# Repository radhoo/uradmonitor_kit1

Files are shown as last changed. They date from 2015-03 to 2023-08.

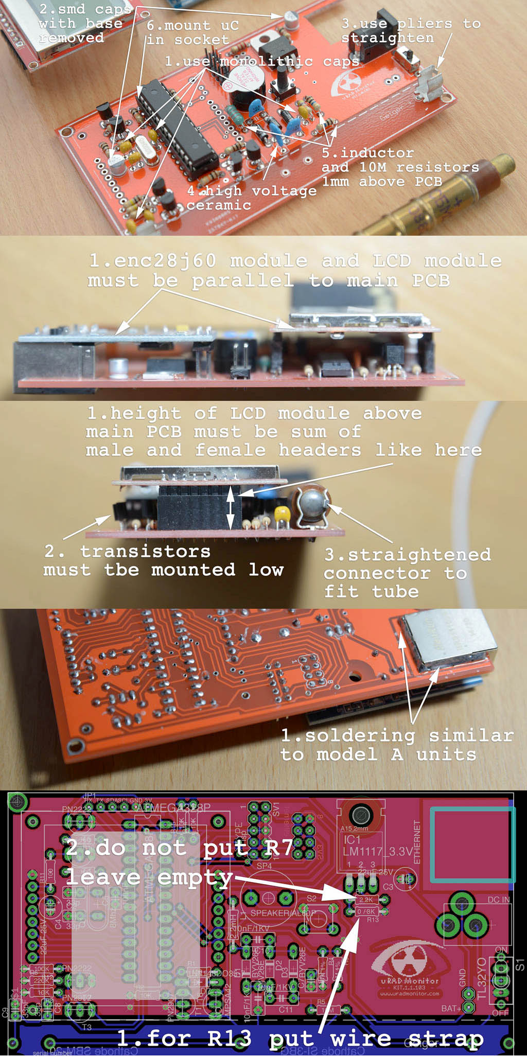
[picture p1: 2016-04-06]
pcb/pcb-1.1.103/pictures/instructions.jpg

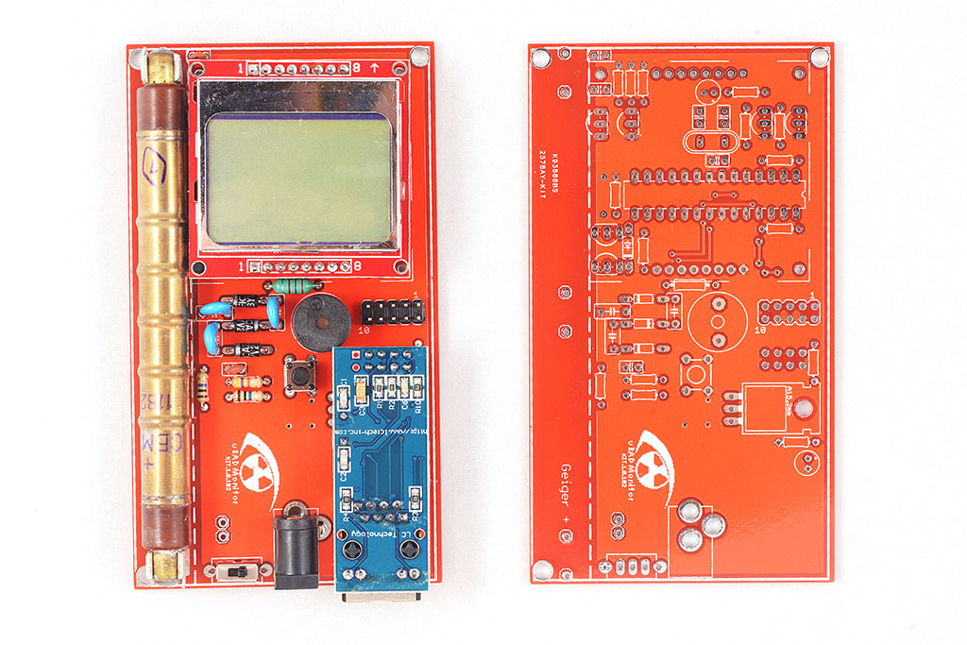
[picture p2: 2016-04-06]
pcb/pcb-1.1.103/pictures/uRADMonitor_KIT1_6.jpg

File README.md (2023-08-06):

# uradmonitor_kit1
A hackable open source DIY Geiger Counter Kit 
with a network interface to the uRADMonitor servers

Project page: http://www.uradmonitor.com/open-source-uradmonitor-kit1/
See the wiki for more details.

Finalist in Hackaday Prize 2017: https://www.uradmonitor.com/finalist-in-hackaday-prize-2017/

DIY KIT1 variants created by makers worldwide:


Firmware compile guide for Windows: https://www.uradmonitor.com/a-tutorial-how-to-compile-kit1-firmware-on-a-windows-machine/ by Wolferl.

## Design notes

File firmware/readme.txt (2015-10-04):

For those of you that want to avoid the hassle of downloading and compiling the code, I have included the compiled code below. 
One variant is a simple, offline code that works without the Ethernet module: uradmonitor-kit1-local.hex 
while the second adds support for Ethernet as well: uradmonitor-kit1-eth.hex

Some instructions on how to burn a hex firmware file to the microcontroller are provided here: 
http://www.pocketmagic.net/how-to-set-the-avr-fusebits/

To correctly burn any of the two hex files into your microcontroller, see the prog.sh script that invokes avrdude. It also sets the fuses for the 8MHz crystal.

Important note:
Code for joining the uRADMonitor network is currently available only on request due to sensitive security details involved. With this code a valid uRADMonitor device ID is also provided.

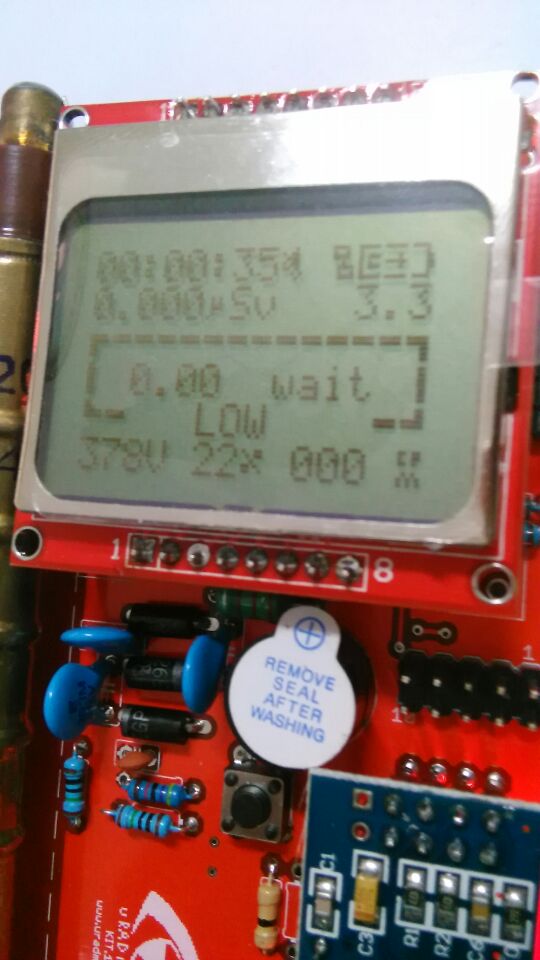
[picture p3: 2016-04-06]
uradmonitor-kit-1.1.103.jpg

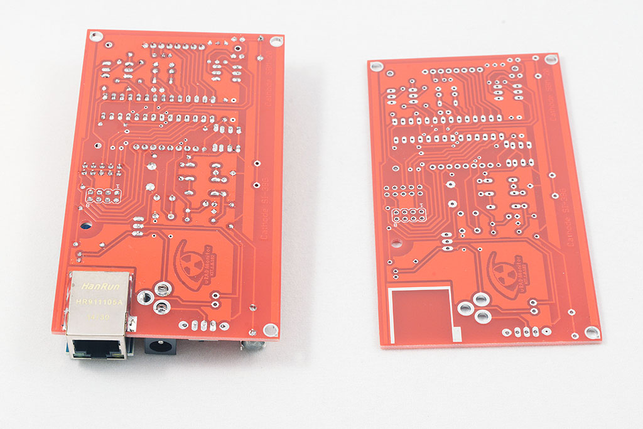
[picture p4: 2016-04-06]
pcb/pcb-1.1.103/pictures/uRADMonitor_KIT1_5.jpg

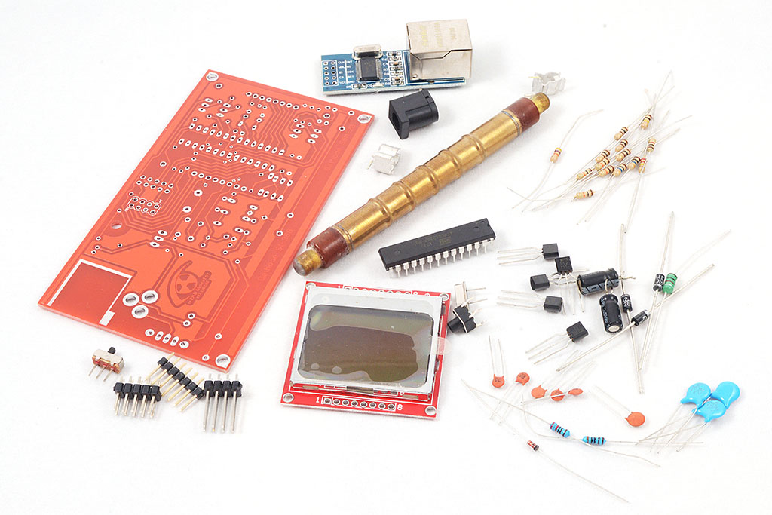
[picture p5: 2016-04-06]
pcb/pcb-1.1.103/pictures/uRADMonitor_KIT1_1.jpg

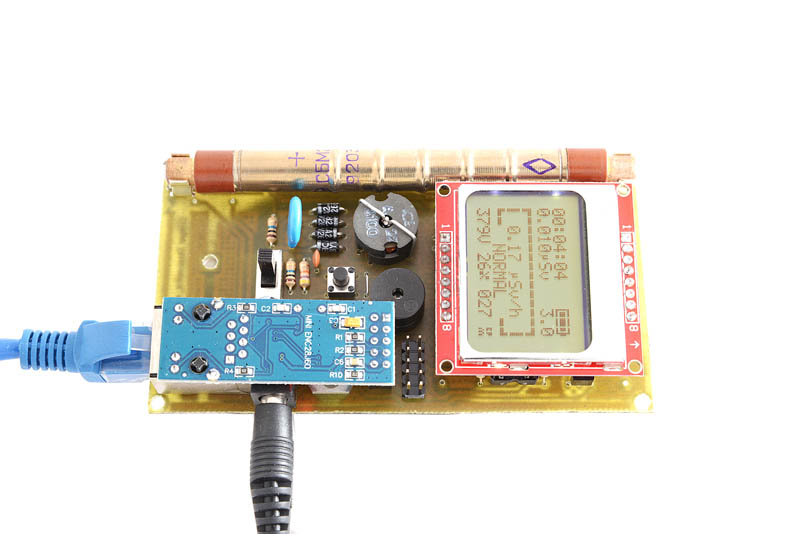
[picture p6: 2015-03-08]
uradmonitor-kit-1.0.jpg

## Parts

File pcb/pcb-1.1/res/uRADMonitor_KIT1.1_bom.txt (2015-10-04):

Partlist exported from /Users/radhoo/Work/pocketmagic/uradmonitor_KIT1/pcb-1.1/dosimeter.sch at 04/10/15 20:23

Assembly variant: 

Qty Value         Device              Parts                                     
1                 LM317TL             IC1                                       
8                 PINHD-1X1           BAT+, BATGND, JP1, JP2, JP3, JP4, JP5, JP6
1                 TAC_SWITCHPTH       S2                                        
1   1N4148DO35-7  1N4148DO35-7        D7                                        
1   2.1MMJACKTHM  2.1MMJACKTHM        U$2                                       
1   2.2K          R-EU_0204/7         R13                                       
1   2.2mH         L-EU0207/10         L1                                        
1   2N2222        2N2222              T2                                        
2   2N2907        2N2907              T3, T6                                    
2   2n2222        2N2222-NPN-TO92-EBC T4, T5                                    
1   3K            R-EU_0204/7         R7                                        
1   8Mhz          XTAL/S              Q1                                        
4   10K           R-EU_0204/7         R2, R8, R14, R15                          
1   10M           R-EU_0204/7         R5                                        
1   10M 1%        R-EU_0204/7         R3                                        
3   10nF/1KV      C5/3                C6, C10, C11                              
1   15nF          C2.5/2              C7                                        
1   22uF 50V      CPOL-EUE2-5         C3                                        
3   33p           C2.5/2              C1, C2, C8                                
1   33pF          C2.5/2              C9                                        
1   47K 1%        R-EU_0204/7         R4                                        
1   47uF 16V      CPOL-EUE2-5         C4                                        
4   100           R-EU_0204/7         R1, R9, R10, R11                          
1   100K          R-EU_0204/7         R12                                       
1   100nF         C2.5/2              C5                                        
1   220K          R-EU_0204/7         R6                                        
1   ATMEGA328P    MEGA8-P             ATMEGA328P                                
3   BYV26E        1N40047.5           D1, D2, D3                                
1   MPSA42        2N2222              T1                                        
1   NOKIA5110     NOKIA5110           U$1                                       
1   SPEAKER/AL60P SPEAKER/AL60P       SP4                                       
1   TL32YO        TL32YO              S1                                        
1   ethernet      MA04-2              SV3                                       
1   isp           MA05-2              SV1

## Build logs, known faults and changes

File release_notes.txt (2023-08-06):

HW 1.2.107 "ARTIFEX" SW124
- ne 10K resistor between data in and vcc pin of the display, it will support better compatibility with different LCD boards, there are more manufacturers doing boards different way and some of them doesn't work properly, this should solve the problem for all.
- footprint space for new Geiger tubes, the "M4011" and the " J305" added.
- factors for the two new tubes added.
- new tubes implemented on the server side

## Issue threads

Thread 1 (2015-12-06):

Tube connectors missing in BOM

berezovskyi, 2015-12-06:
Hi, I looked at the https://github.com/radhoo/uradmonitor_kit1/blob/master/pcb-1.1/res/uRADMonitor_KIT1.1_bom.txt#L7 but found no connectors (slots) in BOM for the SBM-20 tube.

Do you have any hints on how to find them?

radhoo, 2015-12-13:
Hello, please use fuse holders, 6mm diameter as connectors.

berezovskyi, 2015-12-20:
Brilliant, @radhoo! I think the best way for others to find them would be to search for *6.3mm (1/4") fuse clip*

berezovskyi, 2015-12-20:
Littelfuse 01020071Z seems to be a good generic part

radhoo, 2015-12-20:
Yes, and there are very affordable ones on Ebay as well.  I got a bag of
100pcs for just a few dollars.

On Sun, Dec 20, 2015 at 11:58 PM, Andrew Berezovskyi <
notifications@github.com> wrote:

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

Closed 2017-08-05.

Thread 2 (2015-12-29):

Routing incomplete?

madmax76, 2015-12-29:
Hi,

Opening the 1.1 board in Eagle shows me that some traces have not been routed. Is that correct? After manually checking, it seems all is oke, but I want to etch the board, so I need to make sure that no errors are in the board. Seems like the Nokia LCD display has some magic via's on it, that I am unaware of.

Best regards,
Max

radhoo, 2015-12-29:
That is correct, the Nokia display continues those routes. No mistakes here, feel free to etch.

Closed 2015-12-29.

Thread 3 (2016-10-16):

can not remove "old" stations from uradmonitor map

twanek, 2016-10-16:
**simptome:**
when flashing the new firmware, if one does not set the "do not clear eeprom" fusebit parameter, the server allocates a new device id.
so, every time when the firmware is flashed, a "new' device will appear on the map, and the "old" ones still remain. this can clutter the map and could suggest improper device numbers / city. posteriorly impossible for the user to remove them...

**solution:**
it would be nice to have a delete button on the dashboard (or some other way) to delete fictional stations from the map. (or delete automatically the units which are offline more than x days)

jetty840, 2017-06-14:
I've also had it happen once when the fuse is set correctly, but the upload comms corrupted.  Delete feature would be good.

radhoo, 2017-06-26:
The solution was implemented on the server side . ID of "Old" units are being reallocated to new requesters. An ID is labeled "Old" if more than 30 days have passed since the last data was received.

Closed 2017-06-26.

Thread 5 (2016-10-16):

in firmware v122, temperature value has only 1 degree resolution

twanek, 2016-10-16:
i'm not sure if it is from wrong compilation settings, or a bug in the code, but the temperature value is displayed only as int on my device display / local site / server.
so, it has only one degree resolution...  :(

reidor, 2016-12-05:
Replace the following line in bme280.cpp as shown in order to evaluate the temperatur as floating point.

```
void BME280::readSensors(float *temperature, uint32_t *pressure, uint8_t *humidity) {

	//*temperature =  (((t_fine * 5 + 128) >> 8) / 100) ;
	*temperature =  ((float)((t_fine * 5 + 128) >> 8) / 100) ;

```

radhoo, 2017-08-05:
fixed in v123

Closed 2017-08-05.

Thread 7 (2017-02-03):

Silkscreen PCB 1.2.105 - Transistors on HV part

MalteP, 2017-02-03:
On the PCB silkscreen the text for T1 is marked with the wrong type "2N2907" and T6 is marked with "MPSA42" which should be swapped.

radhoo, 2017-02-03:
Yes, you are right. I will fix it soon. Thanks! (please see my other email, I just sent you).

andrew-xdn, 2017-05-21:
Hello! Found the same issue on the image files (uradmonitor_kit1/pcb/1.2.105/circuit/kit1_105_pcb.png, http://www.uradmonitor.com/wordpress/wp-content/uploads/2016/10/pcb_opensource_kit_105_pcb.jpg). It's a little confusing if you use one of the images to mount components.

jetty840, 2017-06-13:
Only caught that one by accident when I was looking for the part in Eagle

radhoo, 2017-08-05:
fixed in 1.2.106

Closed 2017-08-05.

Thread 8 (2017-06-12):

Makefile for non-eclipse users

jetty840, 2017-06-12:
Please add a Makefile:

````
CC=avr-gcc
CFLAGS=-fdata-sections -ffunction-sections -Wall -Wl,-u,vfprintf,--gc-sections -funsigned-char -Os -DF_CPU=8000000 -mmcu=atmega328p
OBJCOPY=avr-objcopy
LIBS=-lprintf_flt -lm

OBJS=uRADMonitor.o  data.o UI.o detectors.o inverter.o DigitalPin.o i2c.o 5110.o morse.o utils.o dhcp_client.o dnslkup.o enc28j60.o ip_arp_udp_tcp.o bme280.o bmp180.o timecounter.o watchdog.o

all:			uRADMonitor.hex

uRADMonitor.hex:	$(OBJS)
			$(CC) $(CFLAGS) $(OBJS) $(LIBS) -o uRADMonitor.elf
			$(OBJCOPY) -O ihex uRADMonitor.elf uRADMonitor.hex

uRADMonitor.o:		uRADMonitor.cpp
			$(CC) $(CFLAGS) -c uRADMonitor.cpp

data.o:			app/data.cpp
			$(CC) $(CFLAGS) -c app/data.cpp

UI.o:			app/UI.cpp
			$(CC) $(CFLAGS) -c app/UI.cpp

detectors.o:		geiger/detectors.cpp
			$(CC) $(CFLAGS) -c geiger/detectors.cpp

inverter.o:		geiger/inverter.cpp
			$(CC) $(CFLAGS) -c geiger/inverter.cpp

DigitalPin.o:		gpio/DigitalPin.cpp
			$(CC) $(CFLAGS) -c gpio/DigitalPin.cpp

i2c.o:			i2c/i2c.cpp
			$(CC) $(CFLAGS) -c i2c/i2c.cpp

5110.o:			lcd/5110.cpp
			$(CC) $(CFLAGS) -c lcd/5110.cpp

morse.o:		misc/morse.cpp
			$(CC) $(CFLAGS) -c misc/morse.cpp

utils.o:		misc/utils.cpp
			$(CC) $(CFLAGS) -c misc/utils.cpp

dhcp_client.o:		net/dhcp_client.cpp
			$(CC) $(CFLAGS) -c net/dhcp_client.cpp

dnslkup.o:		net/dnslkup.cpp
			$(CC) $(CFLAGS) -c net/dnslkup.cpp

enc28j60.o:		net/enc28j60.cpp
			$(CC) $(CFLAGS) -c net/enc28j60.cpp

ip_arp_udp_tcp.o:	net/ip_arp_udp_tcp.cpp
			$(CC) $(CFLAGS) -c net/ip_arp_udp_tcp.cpp

bme280.o:		sensors/bme280.cpp
			$(CC) $(CFLAGS) -c sensors/bme280.cpp

bmp180.o:		sensors/bmp180.cpp
			$(CC) $(CFLAGS) -c sensors/bmp180.cpp

timecounter.o:		time/timecounter.cpp
			$(CC) $(CFLAGS) -c time/timecounter.cpp

watchdog.o:		time/watchdog.cpp
			$(CC) $(CFLAGS) -c time/watchdog.cpp

clean:
			rm -f *.o uRADMonitor.elf

realclean:		clean
			rm -f uRADMonitor.hex
````

radhoo, 2017-08-05:
Thanks, makefile added to v123

Closed 2017-08-05.

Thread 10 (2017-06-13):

Anode resistor

jetty840, 2017-06-13:
Recommended anode resistor for the SBM-20 in the datasheet is 5.1MOhm, however this design has 10M Ohm and most other designs using this tube use a closer value (4.7MOhm).

What would be the effect on detection rate by changing it to closer to the recommended value?  Any other issues?

radhoo, 2017-08-05:
Geiger tube theory paperwork documents the process of selecting the anode resistor beyond the simple datasheet recommendation. The idea is that with an increased resistor, the tube life if prolonged. What is important is to keep the ratio between the anode resistor and the cathode resistor, in order to set the desired amplitude of the output pulse. This has been carefully chosen for the KIT1, but also the other uRADMonitor detectors.

Here is a copy: http://www.rsp-italy.it/Electronics/Databooks/Sensors/_contents/Centronic%20-%20Geiger%20Tube%20Theory%20-%20ISS1.pdf

Closed 2017-08-05.

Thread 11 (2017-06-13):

Inductor specification

jetty840, 2017-06-13:
Purchased a 2.2mH inductor (34Ohm) didn't work well.  Only was able to reach 380V with the inverter, and inverter was unstable and then entered discontinuous mode and voltage started dropping due to the light load.  If left to auto tune, tuned to 90% duty cycle (even if picking 370V as the target).  Also tried varying frequency, same result.

Hand wound indicator (2.3mH - 6Ohm) (i.e. same inductance, less resistance), resulted in the same.

So hand wound a 4.4mH 10.28Ohm (2.7 Q 5.7uF parasitic, 450 turns) around a ferrite core (450 turns).

Now by reducing the frequency to 9KHz, I get a stable region at around 65% duty cycle and can lock on to 400V without any issues.  The increased inductance prevents the boost circuit from entering discontinuous mode.

I suspect the inductance value in the BOM is at the lower limit of marginal, and either should be increased or the inductor used fully specified.

radhoo, 2017-08-05:
The inductor is the 2.2mH 25Ohm Ring Inductance 0.5W size 0410. The duty cycle has been improved in v1.2.106 see the new component values.

Closed 2017-08-05.

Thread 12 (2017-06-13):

Regulator voltage

jetty840, 2017-06-13:
The regulator voltage of 3.0V is too low.  The minimum for the ENC28J60 is 3.1V according to the datasheet, and I've noticed erratic behavior in the 2.9V - 3.0V range which is around the level of the low battery indicator.  For example, at 2.95V my ENC28J60 won't startup 50% of the time.

I suggest 3.3V for the regulator if using ethernet.

radhoo, 2017-08-05:
v1.2.105 and newer uses the AMS1117 3.3V regulator.

Closed 2017-08-05.

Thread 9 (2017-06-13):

Tube length

jetty840, 2017-06-13:
The SBM-20 I had (marked SBM-20) was too large to fit the PCB and I needed to respin it.

According to the lengths on:  https://www.gstube.com/data/2398/, I have a SBM-20, and KIT1 is for a SBM-20U

I received the tube with my MightyOhm kit about 2 years ago and it fitted that board, so suspect there maybe multiple sizes of double end capped tube labelled SBM-20 as the SBM-20U has one end cap missing

Recommend adding a 2nd position for the clip on the board for the larger length tube.

radhoo, 2017-08-05:
The design is for SBM20. The tube fits fine, please see the pictures.
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

Closed 2017-08-05.

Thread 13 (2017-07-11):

Resistor value changes to reduce overall current consumption

Wolferl1, 2017-07-11:
I'd like to suggest some resistor value changes which allow for reduced overall current consumption of the KIT1 without impairing its performance. I tested all if these changes successfully on my KIT1.

1. The base resistor R9 to T4 for the LED backlight is IMHO much too low with 100 ohms.
I changed it to 2k7, and T4 still saturates to 0,05V when the backlight LEDs are on. I assume a 4k7 resistor will be just fine here.

2. The same goes with the base resistor R10 for T5 (beeper). I also used a 2k7 here (and could also easily be 4k7). There is no noticable decrease of beeper sound volume.

3. With the standard values, the pulse width for SBM20 tube anode voltage generation was about 64% (whole unit needed 42mA at 5V). The voltage divider R3 and R4 could be made better with 47Mohms and 220kOhms, greatly reducing the load here.

4. R1's value is way too low. Originally, I scoped a base current of 15mA into T1 (when T1 is turned on). For an estimated "on-state" collector current of 100mA and a MPSA42 has a hFE of at least 40, so a base current of about 2mA should be ok. That gives a base resistor value of about 2k.
I tried successfully a value of 1k5 instead of 100 ohms.

All these changes do not require a software modification.

Doing this, the HV converter pulse width reduced to about 43%, and the unit only draws 25mA now.

radhoo, 2017-08-05:
Thank you. Here are the modifications fixing these issues in 1.2.106 and my comments:
1. R9 changed to 4.7K
2. R10 changed to 4.7K
3. I used 22M/100K for R3 and R4. Centronics Geiger tube theory recommends a certain ratio between these two, that is also important for getting the right pulse amplitude for the following blocks. The change 22M/100K didn't change the duty load. So I prefer to go with 10M/47K as these are more common components.
4. R1 was changed to a multitude of values: 180, 330, 470, 1K, 2.2K and the results were bad. This was kept to the original 100Ohm value.

With these changes, the pulse width was reduced to 43% and on some units to 40%. Please keep in mind that this is not the duty cycle that the switching transistor sees. The switching transistor, MPSA42, sees a reduced duty cycle due to the blocker PNP transistor used to collapse the magnetic field faster, and so obtaining higher amplitude spikes across the inductor, needed to make the jump from 3.3V to 380V. Still this improvement is important, as some inductors were at their upper limit for providing the needed voltage and now the margin is bigger.

The power consumption also improved negligibly.

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

Wolferl1, 2017-08-05:
Hi Radu,
Thank you for reviewing this. I agree with you at points 1 and 2.
With point 3, I beg to differ *g*
The resistor divider network 10M / 47k is only for sensing the tube voltage. This 10M is IMHO an unnecessary high load. I now use 47M and 220k with very good results. Don't confuse this with the 2nd 10M resistor which is the anoder working resistor for the tube. This resistor has already the correct 10M value.
However I do agree with you that 22M or even 47M are bigger (especially the 500V capable ones) and are not that common.

As for point 4, it could be that you needed lower values for R1 because the load on the HV line is high than on my KIT1.

Kind regards,
Wolferl

radhoo, 2017-08-05:
Sorry I wrote this in a hurry and did a mistake. R3/R4 is for the voltage feedback. Allow me to edit the answer to avoid any confusions.

radhoo, 2017-08-05:
Done. Your contribution helped this design a lot. Getting the duty to 40-43% solves the issue some other builders where having identifying the exact coils I've used.
For point 4 I also agree with your input, and was prepared to change it as well, then I did some tests on 2-3 devices and I was unable to get it right. More testing will be needed.  Values close to 100Ohm worked fine, but getting aways quickly created problems.

Closed 2017-08-05.

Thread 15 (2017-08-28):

Minor issue about humidity

Wolferl1, 2017-08-28:
When using your KIT1 with BME280 sensor, humidity is formatted as a 2 decimal places float number...the sensor only returns integer humidity percentages.
Also, in file uradmonitor.cpp on line #414 it says "humidty" instead of "humidity".

Wolferl1, 2018-07-26:
Hi Radu, any ideas when a new version (124?) will be uploaded?

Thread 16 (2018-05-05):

aux_detectorFactor for GEIGER_TUBE_SBM20 - CPM to µSv/h conversion

Trickx, 2018-05-05:
Hi,

I'm trying to calibrate my Geiger counter based on a SBM20 tube.
Within your code, I found the conversion factor of 0.006315 from CPM (counts per minute) towards µSievert/h. (Invers conversion factor: 158,35.)
There are various conversion factors being reported in the web. This one is one of the famous ones.

Did you somehow calibrate your device? How did you derive this factor?

Actually I gave up to calculate the conversion factor.
I think I read all of the discussions about this topic in the English or German intrnet,
so I tried to find a reference for my location and calibrate it that way.

I'm located in Lehrte, Germany and see about 18 ticks in average with my SBM20 tube.
The German Bundesamt für Strahlenschutz (Federal Office for Radiation Protection - BfS) operates some monitoring stations acros Germany. Luckily there is one located in Lehrte, see
https://odlinfo.bfs.de/DE/aktuelles/messstelle/032530101.html
The average of this station seems to be around ~0,075 Sv/h.
This leads to a conversion factor of ~ 0,0041666 (inverse= 240).
Unfortuantely, I could not find more details about the station itself.

On https://www.uradmonitor.com/ I found a station located in Uelzen.
Unfortunately, I could not easily generate a deep link, so you need to search for it on the map.
However, the station's average is 0.10µSv/h.

The BfS reports for Uelzen 0,066µSv/h, see
https://odlinfo.bfs.de/DE/aktuelles/messstelle/033600252.html

So there is a mismatch of the reported values.
Interestingly, it is the same deviation as I would see with the conversion factor of this project.

If the uradmonitor from Uelzen would use my conversion factor instead of the one from this code,
the calculated radiation dosis for Uelzen becomes:
0.10µSv/h * 158,35 / 240 = 0,0657µSv/h, which is quit close to the value reported by BfS.

Of course this is just an indication but I think this demonstrates a common error.
I did not spend the time to check more stations.

I just would like to get more details about the calibration done for this project and why this way was choosen.

Thank you in advance,
Trickx

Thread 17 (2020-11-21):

Missing Documentation and BOM

mnemocron, 2020-11-21:
The project in itself is a very neat thing to build. But can you please add more documentation.
Just from the files alone I was not able to order the correct parts.

The schematics do not give away the exact part-nr. for the components.
This is tricky not only for capacitors but mostly for the electromechanical components like the fuse-clips or the switch.

Furthermore, I managed to order the wrong LCD module - the one from Sparkfun - as opposed to the cheaper Chinese one with a _different pinout_.
Then I ordered a 1117 Regulator as a THT part because many images online contain a THT regulator.
But the most recent revision of the PCB (`v1.2.106`) apparently features an SMT regulator.

.. I hope you see my point.
**Please add at least a proper BOM** with reference to the hardware revision (eg. `v1.2.106`)

Here is a start. This is what I ordered from digi-key

[https://octopart.com/bom-tool/xPA7yJNx](https://octopart.com/bom-tool/xPA7yJNx)
> (note: that the BOM is incomplete and does contain extra parts and wrong parts)

---

Another part you should document is, how you compile and upload the code to the board.
The URL in the `README` is outdated and does not work anymore.
I used the following commands in WSL to compile the code:

```bash
sudo apt install make avr-gcc avr-libc gcc-avr
cd ./code
make
```

and the following commands in PowerShell to upload the code to the board using ASP

```powershell
& 'C:\Program Files (x86)\Arduino\hardware\tools\avr/bin/avrdude' -CC:'\Program Files (x86)\Arduino\hardware\tools\avr/etc/avrdude.conf' -v -patmega328p -cusbasp -Pusb -Uflash:w:C:\users\simon\Downloads\uRADMonitor.hex:i
```
or short
```powershell
avrdude.exe -Cavrdude.conf -v -patmega328p -cusbasp -Pusb -Uflash:w:uRADMonitor.hex:i
```

---

And maybe you could document how the Software works.
What the LCD displays and what the button does.
This is actually covered in the Youtube Video linked somewhere in the repo.

radhoo, 2020-11-21:
Hello Simon,

Thanks for the nice feedback.

There are a few articles on the uRADMonitor blog that bring in the missing pieces, see: https://www.uradmonitor.com/blog/?s=kit1

There was also a article on how to compile the KIT1 code  but it got deleted with no recovery due to an unexpected situation.

If interested feel free to give back to the community yourself, and write a quick guide or even a blog post on the uRADMonitor blog.

Let me know if interested, that would help others like you with what you learned so far.

mnemocron, 2020-11-21:
Thanks for the hint with the forum. When I was researching my BOM, I quickly left the forum website as it did not seem to contain the information that I need (still doesn't).

I just looked at the articles you linked.
The issue with the articles is: they do not contain a proper BOM.
They either link back to this repo on Github or they contain some sort of "tutorial" for an outdated hardware.

But there is a post that describes how to program it at least (using USB ASP):
[https://www.uradmonitor.com/open-source-uradmonitor-kit1/](https://www.uradmonitor.com/open-source-uradmonitor-kit1/)

And a post describing what the firmware does:
[https://www.uradmonitor.com/model-kit1-production-ready/](https://www.uradmonitor.com/model-kit1-production-ready/)

I should not have to research a BOM from some Forum posts that are not linked inside the original repo.

So yes, I would like to share my findings as soon as I have a Kit running. (In a way I already did here)
Unfortunately I now need to order again...
It just feels odd that you encourage me to reverse engineer something that you already know.

IkaSGC, 2020-11-21:
If someone could bring quality instructions on how to put it together and flash using windows, it would be amazing. I have theoretically materials for several uRad monitors at home. I've passed one so far, but I can't get anything out of it. Even the display shows nothing. Obviously an error occurred somewhere, but I can't figure it out with the little information I found.

radhoo, 2020-11-21:
Also see: https://www.uradmonitor.com/topic/opensource-kit1-firmware/ and the rest of the forum.

radhoo, 2020-11-21:
For compiling on Windows there already is a tutorial here: https://www.uradmonitor.com/a-tutorial-how-to-compile-kit1-firmware-on-a-windows-machine/

mnemocron, 2020-12-26:
a wonderful good morning everyone,

I have finished up the BOM on Octopart.
I used the [bom.html](https://github.com/radhoo/uradmonitor_kit1/blob/master/pcb/1.2.106/bom.html) from the original repository and added actual part numbers (for digikey).

It would be helpful if you could copy / paste the below markdown BOM to your repos Wiki or Readme.md

BOM on [Octopart](https://octopart.com/bom-tool/xPA7yJNx)

BOM as Markdown:

| Qty | Line Item          | Manufacturer        | MPN                | Schematic Reference | Supplier                                            | Description                                                           | SKU                     | Unit Price (@ Batch Size: 2) | URL                                                                                                    | Unit Price (@ Batch Size: 2) [Lowest Price   (Overall)] | Line Total [Lowest Price (Overall)] |
|-----|--------------------|---------------------|--------------------|---------------------|-----------------------------------------------------|-----------------------------------------------------------------------|-------------------------|------------------------------|--------------------------------------------------------------------------------------------------------|---------------------------------------------------------|-------------------------------------|
|     |                    |                     |                    |                     |                                                     |                                                                       | Digi-Key                | Digi-Key                     | Digi-Key                                                                                               |                                                         |                                     |
| 1   | 1N4148TR           | Vishay              | 1N4148TR           | D7                  |                                                     | Diode, Small Signal; 300 mA; 100 V                                    | 1N4148VSCT-ND           | 0.08896                      | https://octopart.com/click/track?ai=8237&sig=09ebca2&sid=459&ppid=73&vpid=188125481&ct=offers          | 0.004003                                                | 0.004003                            |
| 3   | PN2222ATA          | ON Semiconductor    | PN2222ATA          | T2, T4, T5          |                                                     | NPN 625 mW 40 V 1 A Through Hole                                      | PN2222ATACT-ND          | 0.204608                     | https://octopart.com/click/track?ai=8237&sig=0d3e9e8&sid=459&ppid=84409647&vpid=452472732&ct=offers    | 0.119307                                                | 0.357922                            |
| 2   | PN2907ATAR         | ON Semiconductor    | PN2907ATAR         | T3, T6              |                                                     | 60 V 800 mA Through Hole PNP                                          | PN2907ATARCT-ND         | 0.231296                     | https://octopart.com/click/track?ai=8237&sig=083ef36&sid=459&ppid=84409654&vpid=452472745&ct=offers    | 0.032292                                                | 0.064585                            |
| 1   | ATMEGA328P-PU      | Microchip           | ATMEGA328P-PU      | ATMEGA328P          | (with bootloader flashed) ebay.com / aliexpress.com | 8 Bit MCU (Arduino Bootloader optional)                               | ATMEGA328P-PU-ND        | 1.850368                     | https://octopart.com/click/track?ai=8237&sig=04b47fc&sid=459&ppid=77760224&vpid=408716895&ct=offers    | 1.75607                                                 | 1.75607                             |
| 3   | BYV26E-TR          | Vishay              | BYV26E-TR          | D1, D2, D3          |                                                     | Diode, Ultrafast; 2.5 V                                               | BYV26ECT-ND             | 0.498176                     | https://octopart.com/click/track?ai=8237&sig=02c1c43&sid=459&ppid=39446776&vpid=189200847&ct=offers    | 0.148563                                                | 0.44569                             |
| 1   | MPSA42             | ON Semiconductor    | MPSA42             | T1                  |                                                     | NPN 625 mW 300V 500mA Through Hole                                    | MPSA42FS-ND             | 0.391424                     | https://octopart.com/click/track?c=1&ai=8237&sig=00c6b34&sid=459&ppid=5050&vpid=452471303&ct=offers    | 0.048661                                                | 0.048661                            |
| 4   | CFR-25JB-52-10K    | Yageo               | CFR-25JB-52-10K    | R2, R8, R14, R15    |                                                     | 10kOhm 1/4W 5% Axial                                                  | 10KQBK-ND               | 0.08896                      | https://octopart.com/click/track?ai=8237&sig=0e1eb73&sid=459&ppid=22569022&vpid=39633415&ct=offers     | 0.08896                                                 | 0.35584                             |
| 2   | CFR-25JB-52-10M    | Yageo               | CFR-25JB-52-10M    | R3, R5              |                                                     | 10MOhm 1/4W 5% Axial                                                  | 10MQBK-ND               | 0.08896                      | https://octopart.com/click/track?c=1&ai=8237&sig=0d9b6ae&sid=459&ppid=22569023&vpid=39633416&ct=offers | 0.08896                                                 | 0.17792                             |
| 1   | CFR-25JB-52-47K    | Yageo               | CFR-25JB-52-47K    | R4                  |                                                     | 47kOhm 1/4W 5% Axial                                                  | 47KQBK-ND               | 0.08896                      | https://octopart.com/click/track?ai=8237&sig=0d75371&sid=459&ppid=22569129&vpid=39633525&ct=offers     | 0.08896                                                 | 0.08896                             |
| 4   | CFR-25JB-52-100R   | Yageo               | CFR-25JB-52-100R   | R1, R11             |                                                     | 100Ohm 1/4W 5% Axial                                                  | 100QBK-ND               | 0.08896                      | https://octopart.com/click/track?ai=8237&sig=08cfce1&sid=459&ppid=16252071&vpid=39633414&ct=offers     | 0.08896                                                 | 0.35584                             |
| 1   | CFR-25JB-52-100K   | Yageo               | CFR-25JB-52-100K   | R12                 |                                                     | 100k Ohm 5% 1/4W Axial                                                | 100KQBK-ND              | 0.08896                      | https://octopart.com/click/track?ai=8237&sig=0c5f370&sid=459&ppid=16252070&vpid=39633413&ct=offers     | 0.08896                                                 | 0.08896                             |
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
mnemocron, 2020-12-26:
@IkaSGC just an idea. Which LCD Modules do you have?
I actually bought the more expensive Sparkfun modules. But they have the wrong pinout, different from the Chinese ones you find on aliexpress. When I rewired the LDC module with the help of the schematics and some breadboard wires it worked.

IkaSGC, 2020-12-26:
@mnemocron  I bought these modules.

https://www.aliexpress.com/item/32526061324.html?spm=a2g0s.9042311.0.0.27424c4dxcoCrr

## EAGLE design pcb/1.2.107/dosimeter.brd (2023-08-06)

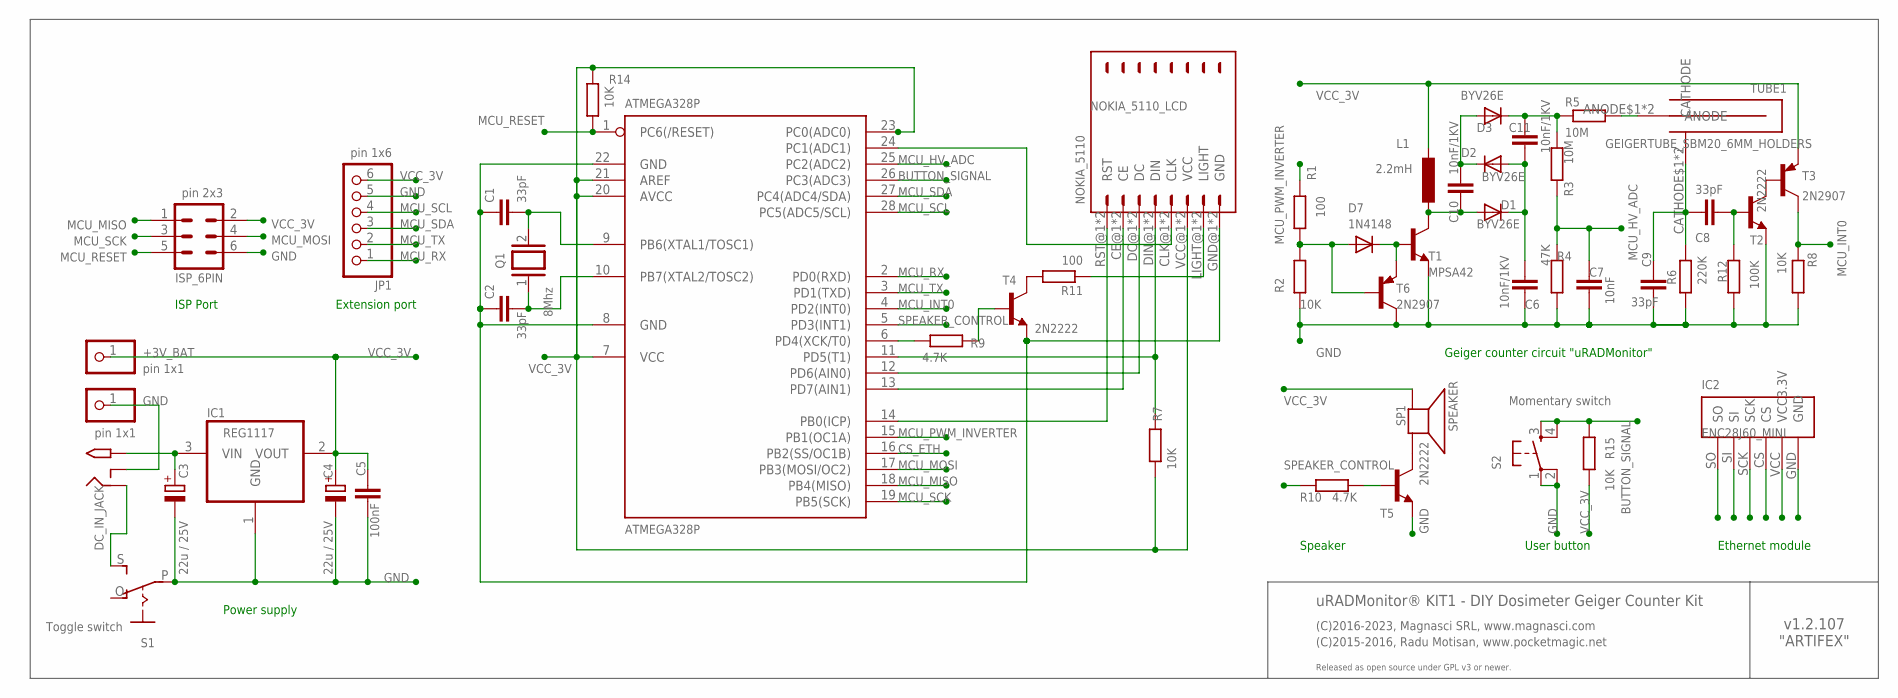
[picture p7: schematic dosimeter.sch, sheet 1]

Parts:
+3V_BAT: pin 1x1; 1X01
ATMEGA328P: ATMEGA328P; DIL28-3
C1, C2, C8, C9: 33pF; C2.5-2
C3, C4: 22u / 25V; TT2D4L
C5: 100nF; C2.5-2
C6, C10, C11: 10nF/1KV; C5B3
C7: 10nF; C2.5-2
D1, D2, D3: BYV26E; DO41-7.6
D7: 1N4148; D-5
DC_IN_JACK: DC IN JACK; PJ-102A
GND: pin 1x1; 1X01
IC1: REG1117; SOT223
IC2: ENC28J60_MINI
ISP_6PIN: pin 2x3; MA03-2
JP1: pin 1x6; 1X06-CLEAN
L1: 2.2mH; 0207/10
NOKIA_5110: NOKIA_5110_LCD; NOKIA5110
Q1: 8Mhz; QS
R1, R11: 100; 0204/7
R2, R7, R8, R14, R15: 10K; 0204/7
R3, R5: 10M; 0204/7
R4: 47K; 0204/7
R6: 220K; 0204/7
R9, R10: 4.7K; 0204/7
R12: 100K; 0204/7
S1: Toggle switch; EG1218
S2: Momentary switch; TACTILE-PTH
SP1: SPEAKER; AL60P
T1: MPSA42; TO92-EBC-OVAL
T2, T4, T5: 2N2222; TO92-EBC
T3, T6: 2N2907; TO92-EBC-OVAL
TUBE1: GEIGERTUBE_SBM20_6MM_HOLDERS

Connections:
BUTTON_SIGNAL: ATMEGA328P.26 (PC3(ADC3)), R15.1, S2.3, S2.4
CS_ETH: ATMEGA328P.16 (PB2(SS/OC1B)), IC2.CS
GND: ATMEGA328P.8 (GND), ATMEGA328P.22 (GND), C1.1, C2.1, C3.-, C4.-, C5.1, C6.2, C7.1, C9.2, IC1.1 (GND), IC2.GND, ISP_6PIN.6, JP1.5, NOKIA_5110.GND@1 (GND), NOKIA_5110.GND@2 (GND), R2.1, R4.2, R6.1, R8.2, R12.2, S1.P, S2.1, S2.2, T1.E, T2.E, T4.E, T5.E, T6.C
MCU_HV_ADC: ATMEGA328P.25 (PC2(ADC2)), C7.2, R3.1, R4.1
MCU_INT0: ATMEGA328P.4 (PD2(INT0)), R8.1, T3.C
MCU_MISO: ATMEGA328P.18 (PB4(MISO)), IC2.SO, ISP_6PIN.1
MCU_MOSI: ATMEGA328P.17 (PB3(MOSI/OC2)), IC2.SI, ISP_6PIN.4
MCU_PWM_INVERTER: ATMEGA328P.15 (PB1(OC1A)), R1.1
MCU_RESET: ATMEGA328P.1 (PC6(/RESET)), ISP_6PIN.5, R14.1
MCU_RX: ATMEGA328P.2 (PD0(RXD)), JP1.1
MCU_SCK: ATMEGA328P.19 (PB5(SCK)), IC2.SCK, ISP_6PIN.3
MCU_SCL: ATMEGA328P.28 (PC5(ADC5/SCL)), JP1.4
MCU_SDA: ATMEGA328P.27 (PC4(ADC4/SDA)), JP1.3
MCU_TX: ATMEGA328P.3 (PD1(TXD)), JP1.2
unnamed: ATMEGA328P.9 (PB6(XTAL1/TOSC1)), C1.2, Q1.2
unnamed: ATMEGA328P.10 (PB7(XTAL2/TOSC2)), C2.2, Q1.1
unnamed: R11.2, T4.C
unnamed: R5.2, TUBE1.ANODE$1 (ANODE), TUBE1.ANODE$2 (ANODE)
unnamed: R9.2, T4.B
unnamed: NOKIA_5110.LIGHT@1 (LIGHT), NOKIA_5110.LIGHT@2 (LIGHT), R11.1
unnamed: C10.2, D1.A, L1.2, T1.C
unnamed: ATMEGA328P.24 (PC1(ADC1)), NOKIA_5110.CLK@1 (CLK), NOKIA_5110.CLK@2 (CLK)
unnamed: DC_IN_JACK.RING, S1.S
unnamed: C10.1, D2.C, D3.A
unnamed: DC_IN_JACK.RING_SW, GND.1
unnamed: ATMEGA328P.11 (PD5(T1)), NOKIA_5110.DIN@1 (DIN), NOKIA_5110.DIN@2 (DIN), R7.2
unnamed: ATMEGA328P.12 (PD6(AIN0)), NOKIA_5110.DC@1 (DC), NOKIA_5110.DC@2 (DC)
unnamed: ATMEGA328P.13 (PD7(AIN1)), NOKIA_5110.CE@1 (CE), NOKIA_5110.CE@2 (CE)
unnamed: ATMEGA328P.14 (PB0(ICP)), NOKIA_5110.RST@1 (RST), NOKIA_5110.RST@2 (RST)
unnamed: D7.A, R1.2, R2.2, T6.B
unnamed: C3.+, DC_IN_JACK.TIP, IC1.3 (VIN)
unnamed: C6.1, C11.2, D1.C, D2.A
unnamed: C11.1, D3.C, R3.2, R5.1
unnamed: ATMEGA328P.6 (PD4(XCK/T0)), R9.1
unnamed: SP1.2 (-), T5.C
unnamed: R10.2, T5.B
unnamed: C8.2, C9.1, R6.2, TUBE1.CATHODE$1 (CATHODE), TUBE1.CATHODE$2 (CATHODE)
unnamed: C8.1, R12.1, T2.B
unnamed: T2.C, T3.B
unnamed: D7.C, T1.B, T6.E
SPEAKER_CONTROL: ATMEGA328P.5 (PD3(INT1)), R10.1
VCC_3V: +3V_BAT.1, ATMEGA328P.7 (VCC), ATMEGA328P.20 (AVCC), ATMEGA328P.21 (AREF), ATMEGA328P.23 (PC0(ADC0)), C4.+, C5.2, IC1.2 (VOUT), IC2.VCC (VCC3.3V), ISP_6PIN.2, JP1.6, L1.1, NOKIA_5110.VCC@1 (VCC), NOKIA_5110.VCC@2 (VCC), R7.1, R14.2, R15.2, SP1.1 (+), T3.E

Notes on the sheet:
uRADMonitor® KIT1 - DIY Dosimeter Geiger Counter Kit
Power supply
Speaker
User button
Geiger counter circuit "uRADMonitor"
Extension port
ISP Port
Ethernet module
(C)2015-2016, Radu Motisan, www.pocketmagic.net
Released as open source under GPL v3 or newer.
v1.2.107 "ARTIFEX"
(C)2016-2023, Magnasci SRL, www.magnasci.com

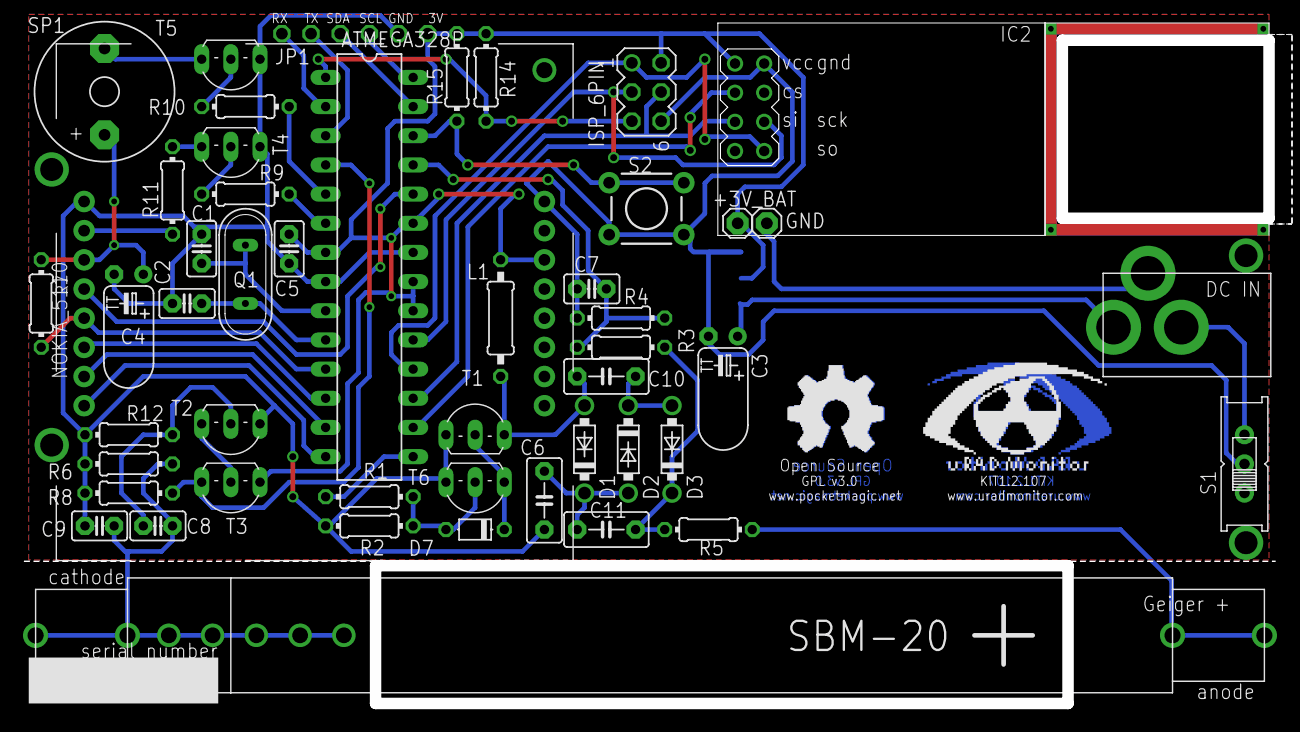
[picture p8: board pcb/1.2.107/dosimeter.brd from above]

Board: 2 copper layers, 109.0 x 57.8 mm, 50 parts (1 on the bottom side), 42 nets.

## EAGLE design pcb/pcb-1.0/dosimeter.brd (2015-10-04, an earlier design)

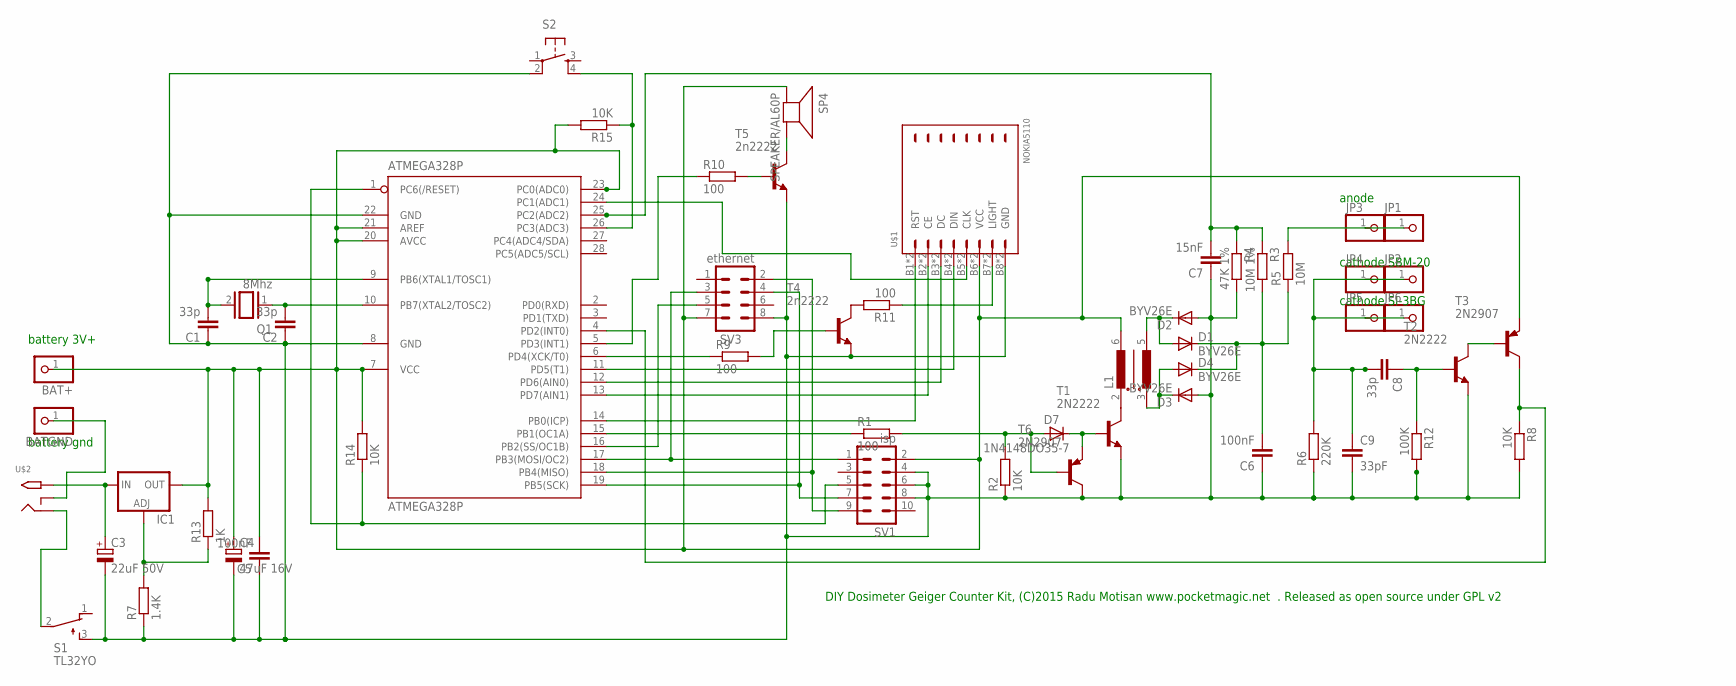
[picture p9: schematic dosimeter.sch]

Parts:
ATMEGA328P: ATMEGA328P; DIL28-3
BAT+: PINHD-1X1; 1X01
BATGND: PINHD-1X1; 1X01
C1, C2, C8: 33p; C2.5-2
C3: 22uF 50V; E2-5
C4: 47uF 16V; E2-5
C5: 100nF; C2.5-2
C6: 100nF; C5B3
C7: 15nF; C2.5-2
C9: 33pF; C2.5-2
D1, D2, D3, D4: BYV26E; D-7.5
D7: 1N4148DO35-7; DO35-7
IC1: LM317TL; 317TL
JP1, JP2, JP3, JP4, JP5, JP6: PINHD-1X1; 1X01
L1: RM6-2; RM5-4
Q1: 8Mhz; QS
R1, R9, R10, R11: 100; 0204/7
R2, R8, R14, R15: 10K; 0204/7
R3: 10M 1%; 0204/7
R4: 47K 1%; 0204/7
R5: 10M; 0204/7
R6: 220K; 0204/7
R7: 1.4K; 0204/7
R12: 100K; 0204/7
R13: 1K; 0204/7
S1: TL32YO; TL3XYO
S2: TAC_SWITCHPTH; TACTILE-PTH
SP4: SPEAKER/AL60P; AL60P
SV1: isp; MA05-2
SV3: ethernet; MA04-2
T1, T2: 2N2222; TO92-EBC-OVAL
T3, T6: 2N2907; TO92-EBC-OVAL
T4, T5: 2n2222; TO92-EBC
U$1: NOKIA5110
U$2: 2.1MMJACKTHM; PJ-102A

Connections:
unnamed: ATMEGA328P.9 (PB6(XTAL1/TOSC1)), C1.2, Q1.2
unnamed: ATMEGA328P.10 (PB7(XTAL2/TOSC2)), C2.2, Q1.1
unnamed: R11.2, T4.C
unnamed: ATMEGA328P.17 (PB3(MOSI/OC2)), SV1.1, SV3.3
unnamed: ATMEGA328P.16 (PB2(SS/OC1B)), SV3.5
unnamed: ATMEGA328P.18 (PB4(MISO)), SV1.9, SV3.2
unnamed: R9.2, T4.B
unnamed: ATMEGA328P.19 (PB5(SCK)), SV1.7, SV3.4
unnamed: R11.1, U$1.B7 (LIGHT), U$1.T7 (LIGHT)
unnamed: ATMEGA328P.1 (PC6(/RESET)), R14.1, SV1.5
unnamed: ATMEGA328P.8 (GND), ATMEGA328P.22 (GND), C1.1, C2.1, C3.-, C4.-, C5.1, C6.1, C7.1, C9.2, D2.A, D3.A, R2.1, R4.2, R6.1, R7.1, R8.2, R12.2, S1.3 (S), S2.2, SV1.4, SV1.6, SV1.8, SV3.8, T1.E, T2.E, T4.E, T5.E, T6.C, U$1.B8 (GND), U$1.T8 (GND)
unnamed: ATMEGA328P.24 (PC1(ADC1)), U$1.B5 (CLK), U$1.T5 (CLK)
unnamed: ATMEGA328P.26 (PC3(ADC3)), R15.1, S2.4
unnamed: S1.2, U$2.RING
unnamed: JP1.1, JP3.1, R5.2
unnamed: BATGND.1, U$2.RING_SW
unnamed: ATMEGA328P.11 (PD5(T1)), U$1.B4 (DIN), U$1.T4 (DIN)
unnamed: ATMEGA328P.12 (PD6(AIN0)), U$1.B3 (DC), U$1.T3 (DC)
unnamed: ATMEGA328P.13 (PD7(AIN1)), U$1.B2 (CE), U$1.T2 (CE)
unnamed: ATMEGA328P.14 (PB0(ICP)), U$1.B1 (RST), U$1.T1 (RST)
unnamed: ATMEGA328P.7 (VCC), ATMEGA328P.20 (AVCC), ATMEGA328P.21 (AREF), ATMEGA328P.23 (PC0(ADC0)), BAT+.1, C4.+, C5.2, IC1.2 (OUT), L1.6 (W1E), R13.2, R14.2, R15.2, SP4.1 (+), SV1.2, SV3.7, T3.E, U$1.B6 (VCC), U$1.T6 (VCC)
unnamed: ATMEGA328P.15 (PB1(OC1A)), R1.1
unnamed: D7.A, R1.2, R2.2, T6.B
unnamed: C3.+, IC1.3 (IN), U$2.TIP
unnamed: L1.2 (W1A), T1.C
unnamed: D3.C, D4.A, L1.3 (W2A)
unnamed: D1.A, D2.C, L1.5 (W2E)
unnamed: ATMEGA328P.6 (PD4(XCK/T0)), R9.1
unnamed: C6.2, D1.C, D4.C, R3.2, R5.1
unnamed: SP4.2 (-), T5.C
unnamed: R10.2, T5.B
unnamed: ATMEGA328P.5 (PD3(INT1)), R10.1
unnamed: IC1.1 (ADJ), R7.2, R13.1
unnamed: C8.2, C9.1, JP2.1, JP4.1, JP5.1, JP6.1, R6.2
unnamed: ATMEGA328P.25 (PC2(ADC2)), C7.2, R3.1, R4.1
unnamed: C8.1, R12.1, T2.B
unnamed: T2.C, T3.B
unnamed: ATMEGA328P.4 (PD2(INT0)), R8.1, T3.C
unnamed: D7.C, T1.B, T6.E

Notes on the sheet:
DIY Dosimeter Geiger Counter Kit, (C)2015 Radu Motisan www.pocketmagic.net . Released as open source under GPL v2
cathode SBM-20
anode
battery 3V+
battery gnd
cathode SI-3BG

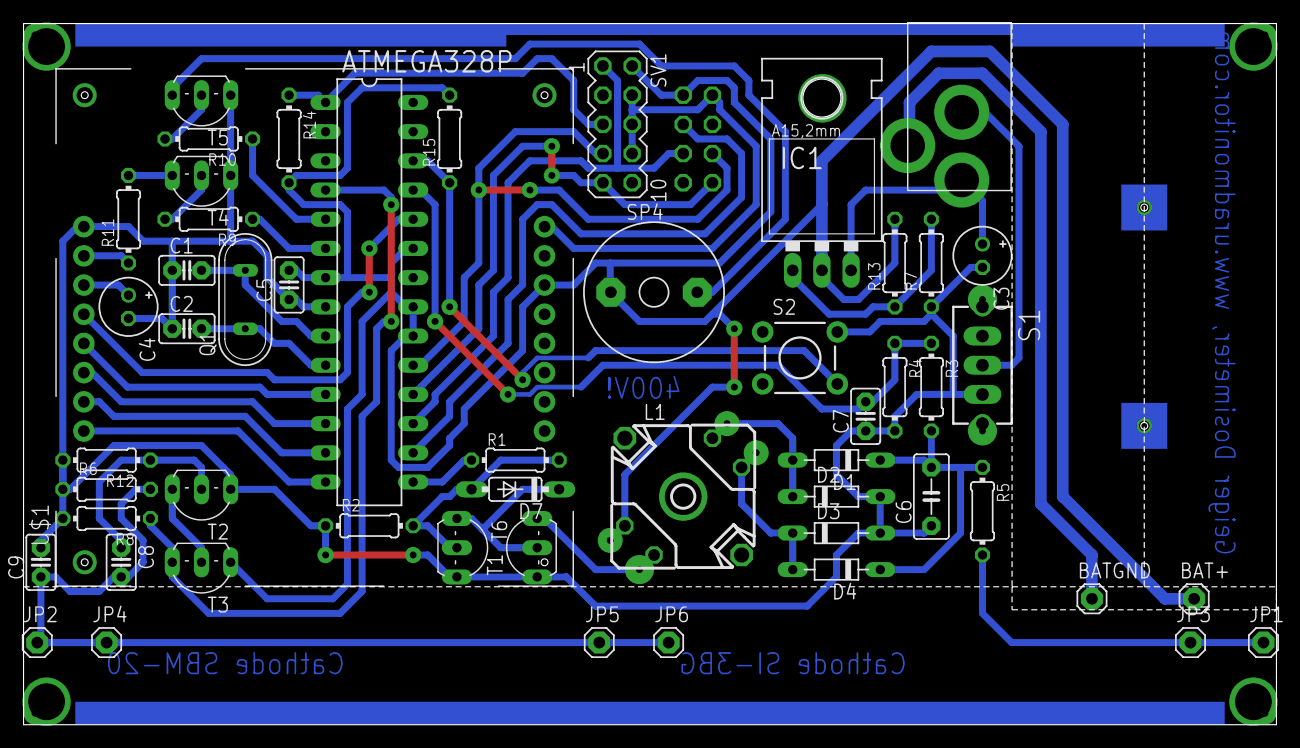
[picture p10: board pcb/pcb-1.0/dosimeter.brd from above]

Board: 2 copper layers, 109.0 x 61.0 mm, 54 parts (1 on the bottom side), 39 nets.

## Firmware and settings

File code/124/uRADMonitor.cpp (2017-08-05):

/**
 *	File:       	uRADMonitor.cpp
 *	Version:  		1.0.121
 *	Date:       	2014
 *	License:		GPL v3
 *	Description:	uRADMonitor main code file
 *	Project:		uRADMonitor KIT1, a hackable digital sensor monitoring tool with network interface
 *
 *	Copyright 2013 by Radu Motisan, radu.motisan@gmail.com
 *	Copyright 2016 by Magnasci SRL, www.magnasci.com
 *
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
 *	You should have received a copy of the GNU General Public License
 *	along with this program.  If not, see <http://www.gnu.org/licenses/>.
 */

#include <avr/io.h>
#include <avr/interrupt.h>
#include <avr/eeprom.h>
#include <avr/wdt.h>
#include <string.h>
#include <stdio.h>
#include <stdlib.h>

#include "app/UI.h"
// local headers
#include "introscreen.h"
#include "lcd/5110.h"
#include "gpio/DigitalPin.h"
#include "time/timecounter.h"
#include "time/watchdog.h"
#include "config.h"
#include "geiger/detectors.h"
#include "misc/utils.h"
#include "misc/morse.h"
#include "misc/expProtocol.h"

// ethernet
#include "net/ip_arp_udp_tcp.h"
#include "net/enc28j60.h"
#include "net/net.h"
#include "net/dhcp_client.h"
#include "net/dnslkup.h"

#define				EEPROM_ADDR_DEVID		0x0		// address when the DEVID is being stored 1024Bytes available on atmega328p	: 4B
#define				EEPROM_ADDR_SENDINT		0x4		// address to store the send interval

/************************************************************************************************************************************************/
/* Global Objects                                                       																		*/
/************************************************************************************************************************************************/
char				buffer[120]		= { 0 };		// general purpose buffer

DigitalPin			speaker(&PORTD, PD3),			// used to create digital pulse on radiation event
					backlight(&PORTD, PD4),			// used to toggle LCD light on and off
					button(&PORTC, PC3, DigitalPin::INPUT), // user button, configured as input pin
					lcdReset(&PORTB, PB0), 			// lcd rst pin
					lcdCE(&PORTD, PD7),				// lcd CE pin
					lcdDC(&PORTD, PD6), 			// lcd DC pin
					lcdDATA(&PORTD, PD5), 			// lcd data pin
					lcdCLK(&PORTC, PC1);			// lcd CLK pin
LCD_5110			lcd(&lcdReset, &lcdCE, &lcdDC, &lcdDATA, &lcdCLK, &backlight);	// handle the LCD ops for drawing content onscreen
TimeCounter			time;
Data				data(&time);
UI					ui(&lcd, &speaker, &button, &data, buffer, sizeof(buffer));// lcd, speaker, button and data, form the GUI for user interaction
Watchdog			wd;								// used to protect device from code deadlocks by issueing an autoreset when needed
Morse				morse;							// used to transmit morse audio signals for communication or general purpose beeps

uint32_t			deviceNumber			= 0;//DEV_NUMBER;	 // If null, Dynamic ID  is enabled . Add a non null value to set number manually
volatile uint32_t 	geigerPulses 			= 0;	// geiger: total number of pulses detected
bool				cmdRefresh = 0;					// if true will refresh display

/************************************************************************************************************************************************/
/* Network interface                                                    																		*/
/************************************************************************************************************************************************/
#ifdef USE_ETHERNET
#define 			ARP_REF_GWMAC 			10		// just an unique request ID returned in the ARP callback
static uint8_t 		ethBuffer[600]			= { 0 };// the big bad ethernet buffer, very memory consuming
static char 		ethParams[120]			= { 0 };// general purpose buffer, will need to hold the upload parameters, careful when using many sensors!
#endif

// simple sound functions
inline void sdelay() { _delay_ms(40); }
inline void sbeep() { speaker = 1; sdelay(); speaker = 0; sdelay(); }
inline void lbeep() { speaker = 1; sdelay(); sdelay(); sdelay(); speaker = 0; sdelay(); }

// callback function called from the timecounter object when a full minute has elapsed
void callback_timeMinute() {}

// called on elapsed second: keep code here light!
void callback_timeSecond() {
	// bigger than 0
	if (time.getTotalSec() > 0 && time.getTotalSec() >= WARMUP) {
		if (time.getTotalSec() % READ_INTERVAL == 0) {
			// compute partial CPM, using time counter 3, that keeps all seconds since last geigerPulses reset to 0
			if (time.getCount(TimeCounter::TIME_COUNTER_3) > 0) {
				data.setGeigerCPM((60 * geigerPulses) / time.getCount(TimeCounter::TIME_COUNTER_3));
				data.setGeigerDose(aux_CPM2uSVh(GEIGER_TUBE, data.getGeigerCPM()));
			}
			// issue READ command every given interval
			data.setStateRead(Data::ENABLED);
		}
		// issue SEND command every given interval
		// if no Ethernet, reset watchdog every time, but if we have Internet, reset it only in the HTTP Client callback
		if (data.getNetworkSendInterval() > 0 && time.getTotalSec() % data.getNetworkSendInterval() == 0) {
			data.setGeigerCPM((60 * geigerPulses) / data.getNetworkSendInterval());
			data.setGeigerDose(aux_CPM2uSVh(GEIGER_TUBE, data.getGeigerCPM()));
			geigerPulses = 0;
			// reinit counter 3, to compute the partical CPM
			time.startCount(TimeCounter::TIME_COUNTER_3);

			if (!data.getStateNetwork())
				wd.wdt_my_reset();
			else {
				// re-set HTTP code
				data.setNetworkHTTPCode(0);
				// ask to send data online
				data.setStateSend(Data::ENABLED);
			}
		}
	}

	// alarm condition
	if (data.getStateAlarm()) {
		if (data.getStateSpeaker()) speaker.toggle(); // // dangerous code to do here
		backlight.toggle();
	}

	// enabled GUI display, that is refresh every second
	cmdRefresh = Data::ENABLED;
}

// watchdog overflow interrupt, set to 1sec
ISR (WDT_vect) { wd.timerEvent(); }

// timer0 overflow interrupt   event to be executed every  2.048ms here when on 8MHz, and every 1.024ms for 16MHz */
ISR (TIMER0_OVF_vect) { time.TimerEvent(); }

// int0 interrupt handler, triggered each time a rising edge is detected on INT0, which on a ATmega8 is PD2
// we have a top limit of 2^32-1 pulses. We don't go over it.
ISR (INT0_vect) {
	geigerPulses++; // count this pulse
	data.setStateBeep(Data::ENABLED);
}

#ifdef USE_ETHERNET
// Callback function for client HTTP connection result
// eg. server reply: {"success":"ok"}
// {"beep":""}
// {"alarm":""}
// {"reset":""}
// {"morse":"msg"}
// {"setid":"82000090"}
// {"sendint":"60"}
void callback_browser(uint16_t webstatuscode, uint16_t datapos, uint16_t len) {
	// 200 means success in connecting to server script: watchdog will NOT reset
	data.setNetworkHTTPCode(webstatuscode);
	// if the server replied OK, we reset the watchdog to prevent auto-reset. This is currently the only point in code where we do this.
	if (webstatuscode == 200) {
		data.incNetworkPacketsOK();
		wd.wdt_my_reset();
		// check reply
		char value[10] = {0}; // this has to be inited, or when parsing we could have extra junk screwing results
		char *serverAnswer = (char *)&(ethBuffer[datapos]);
		if (strstr_P(serverAnswer,PSTR("beep")))
			data.setStateBeep(Data::ENABLED);
		else if (strstr_P(serverAnswer,PSTR("alarm")))
			data.setStateAlarm(Data::ENABLED);
		else if (jsonKeyFind(serverAnswer, "setid", value, 10)) {
			eeprom_busy_wait();
			eeprom_write_dword((uint32_t *) EEPROM_ADDR_DEVID, hex2int(value));
			eeprom_busy_wait();
			aux_softwarereset();
		} else if (jsonKeyFind(serverAnswer, "sendint", value, 10)) {
			data.setNetworkSendInterval(atoi(value));
			eeprom_busy_wait();
			eeprom_write_word((uint16_t *) EEPROM_ADDR_SENDINT, data.getNetworkSendInterval());
			// set WDT reset interval against sendInterval
			wd.wdt_setRebootSeconds(data.getNetworkSendInterval() + WARMUP + 180);
		} else if (jsonKeyFind(serverAnswer, "morse", value, 10)) {
			morse.encode(value);
		} else if (strstr_P(serverAnswer,PSTR("reset"))) {
			aux_softwarereset();
		}
	}
}

// Callback function for ARP requests
void callback_arp(uint8_t *ip __attribute__((unused)), uint8_t reference_number, uint8_t *mac) {
	if (reference_number == ARP_REF_GWMAC)
		memcpy(data.getMACGateway(), mac, 6);
}

// Callback function for incoming pings
void callback_ping(uint8_t *srcip) {
	data.incNetworkPings();
}
#endif

// This function is called upon a HARDWARE RESET, before main() :
void early_run(void) __attribute__((naked)) __attribute__((section(".init3")));

// disable WDT on reboot, to avoid any deadlocks
void early_run(void) {
	Watchdog::wdt_first_disable(); // call as static: object might not be ready yet
}

/************************************************************************************************************************************************/
/* Main entry point                                                    																			*/
/************************************************************************************************************************************************/
 int main(void) {
	// 1.setup watchdog, EEPROM params/Dev ID/Send interval
	wd.wdt_init(WATCHDOG_INTERVAL); // 10min reboot
	eeprom_busy_wait();
	deviceNumber = eeprom_read_dword((uint32_t *) EEPROM_ADDR_DEVID);
	data.setNetworkSendInterval(eeprom_read_word((uint16_t *) EEPROM_ADDR_SENDINT));
	if (data.getNetworkSendInterval() == 0xFFFF || data.getNetworkSendInterval() < 5 || data.getNetworkSendInterval() > 3600)
		data.setNetworkSendInterval(60); // default to 1 min send interval

	// set WDT reset interval against sendInterval
	wd.wdt_setRebootSeconds(data.getNetworkSendInterval() + WARMUP + 180);
	// configure device ID and MAC
	data.setDeviceID_Mac(((uint32_t) DEV_CLASS << 24) | ((uint32_t) deviceNumber & 0x00FFFFFF));

	// 2.CONFIGURE INTERRUPT INT0  to count pulses from Geiger Counter, connected on PIN PD2
	EICRA |= _BV(ISC00) | _BV(ISC01);// Configure INT0 to trigger on RISING EDGE - Instead of MCUCR, you need to use EICRA. mega8:MCUCR , mega328p: EICR
	EIMSK |= _BV(INT0); // Configure INT0 to fire interrupts - Instead of GICR, you need to use EIMSK mega8:GICR , mega328p: EIMSK
	
	// 3.CREATE Timer T0 to count seconds
	time.init(callback_timeSecond, callback_timeMinute);
	// start couting seconds for the partial CPM
	time.startCount(TimeCounter::TIME_COUNTER_3);

	// 4.CREATE Timer T1 PWM to drive inverter for regulated Geiger tube voltage
	data.getInverter().initPWM();

	// 5. init sensors
	morse.init(sbeep, lbeep, sdelay);
	data.initSensors();


	// 6. lcd init goes here
	lcd.init();
	lcd.clear(); lcd.printPictureOnLCD(introScreen); _delay_ms(1000); lcd.clear();
	lcd.send(PSTR("Init ETHERNET\n--------------Connect cable\nand wait15s or press button\nto go offline."));
	lcd.setBacklight(Data::ENABLED);

#ifdef USE_ETHERNET
	// 7.Init ETHERNET
	uint16_t plen = 0, dat_p = 0;
	enc28j60Init(data.getMACLocal()); //initialize enc28j60
	enc28j60PhyWrite(PHLCON, 0x476); // 0x476 is PHLCON LEDA (green)=links status, LEDB (yellow) =receive/transmit (enc28j60 datasheet, page 11)
	// DHCP handling. Get the initial IP. At this point we'll know if the network is ok: cable connected, router ok
	uint8_t rval = 0;
	init_mac(data.getMACLocal());
	//assume net is on unless we cancel
	data.setStateNetwork(Data::ENABLED);
	// DHCP lease loop
	while (rval == 0) {
		plen = enc28j60PacketReceive(sizeof(ethBuffer), ethBuffer);
		sprintf_P(ethParams, PSTR("uRADMonitor-%02X"), data.getMACLocal()[5]);
		rval = packetloop_dhcp_initial_ip_assignment(ethBuffer, plen, data.getMACLocal()[5], ethParams); 	// blocking, can take up to 11sec in a single cycle
		if (!button) {
			data.setStateNetwork(Data::DISABLED); break; // user canceled DHCP lease loop and wants offline mode
		}
	}
	// continue network init
	if (data.getStateNetwork()) {
		// we have an IP, read it
		dhcp_get_my_ip(data.getIPLocal(), data.getIPNetmask(), data.getIPGateway());
		client_ifconfig(data.getIPLocal(), data.getIPNetmask());
		if (data.getIPGateway()[0] == 0)
			data.setStateNetwork(Data::DISABLED);
		else {
			// we have a gateway, find the mac address of the gateway (e.g your dsl router).
			get_mac_with_arp(data.getIPGateway(), ARP_REF_GWMAC, &callback_arp);
			while (get_mac_with_arp_wait()) {
				// to process the ARP reply we must call the packetloop
				plen = enc28j60PacketReceive(sizeof(ethBuffer), ethBuffer);
				packetloop_arp_icmp_tcp(ethBuffer, plen);
				// this takes almost 0sec, in a single cycle
			}
			// count the pings
			register_ping_rec_callback(&callback_ping);
		}
	} else {
		// if network init is not OK, simply power down the enc28j60 module
		powerDown();
	}
#endif
	// we don't check if failed (data.getStateNetwork() = (rval != 0), we assume we're online, and will fail later and reboot via watchdog
	// the only offline scenario is considered when the user specifically pressed the button in the DHCP resolve wait screen
	// if net is on, speaker goes off by default
	data.setStateSpeaker(!data.getStateNetwork());

	// turn LCD light on
	lcd.setBacklight(Data::ENABLED);

	// 8.Main program loop
	while (1) {

		// read sensors, listen to button presses and refresh screen
		ui.loop(&cmdRefresh);

#ifdef USE_ETHERNET

		if (data.getStateNetwork()) {
			// get packets, handle ping and wait for a tcp packet
			plen = enc28j60PacketReceive(sizeof(ethBuffer), ethBuffer);
			// return the position  of the tcp data if there is tcp data part
			dat_p = packetloop_arp_icmp_tcp(ethBuffer, plen);

			if (plen == 0) {
				// First, DNS Request
				if (data.getStateDNS() != Data::DNS_RESOLVED) {
					// before anything else, handle DNS requests
					if (data.getStateDNS() == Data::DNS_IDLE) {
						// only for dnslkup_request we have to check if the link is up.
						if (!enc28j60linkup()) continue;
						data.setStateDNS(Data::DNS_RESOLVING);
						dnslkup_request(ethBuffer, URADMONITOR_SERVER, data.getMACGateway());
						continue;
					}
					if (data.getStateDNS() == Data::DNS_RESOLVING && dnslkup_haveanswer()) {
						data.setStateDNS(Data::DNS_RESOLVED);
						dnslkup_get_ip(data.getIPRemote());
					}
					// retry every half minute if dns-lookup failed:
					if (time.getSec() == 60) data.setStateDNS(Data::DNS_IDLE);
					continue;
				}
				// Next, handle CLIENT Data in case we need to send
				if (data.getStateSend()) {
					// uploading to uRADMonitor network requires authentification with a valid account
					// to get a valid account, register on www.uradmonitor.com/dashboard , then enter your details in config.h
					// do not modify the code below
					sprintf_P(buffer, PSTR("X-User-id:%s\r\nX-User-hash:%s\r\nX-Device-id:%08lX\r\n"), USER_ID, USER_KEY, data.getDeviceID());

					// when sending data, make sure you include the timestamp with each packet, or the server will reject your data
					// see expProtocol.h for the possible sensors supported by the server
#ifdef USE_BME280_SENSOR
					sprintf_P(ethParams, PSTR(ID_TIME_SECONDS"/%lu/"ID_VERSION_HW"/%u/"ID_VERSION_SW"/%u/"
							ID_GEIGER_CPM"/%lu/"ID_INVERTERVOLTAGE_VOLTS"/%u/"ID_INVERTERDUTY_PM"/%u/"
							ID_TEMPERATURE_CELSIUS"/%.2f/"ID_PRESSURE_PASCALS"/%lu/"ID_HUMIDITY_RH"/%.2f/"ID_TUBE"/%u"),
							time.getTotalSec(), (uint8_t)VER_HW, (uint8_t)VER_SW,
							data.getGeigerCPM(),data.getInverterVoltage(), data.getInverterDuty(),
							data.getTemperature(), data.getPressure(), data.getHumidity(), GEIGER_TUBE
						);
#else
					sprintf_P(ethParams, PSTR(ID_TIME_SECONDS"/%lu/"ID_VERSION_HW"/%u/"ID_VERSION_SW"/%u/"
												ID_GEIGER_CPM"/%lu/"ID_INVERTERVOLTAGE_VOLTS"/%u/"ID_INVERTERDUTY_PM"/%u/"ID_TUBE"/%u"),
							time.getTotalSec(), (uint8_t)VER_HW, (uint8_t)VER_SW,
							data.getGeigerCPM(),data.getInverterVoltage(), data.getInverterDuty(), GEIGER_TUBE
						);

#endif
					// send data as HTTP POST
					client_http_post(PSTR(URADMONITOR_SCRIPT), ethParams, PSTR(URADMONITOR_SERVER), buffer, NULL, &callback_browser, data.getIPRemote(), data.getMACGateway() );
					// count all outbound packets
					data.incNetworkPacketsTotal();
					// mark sending job done
					data.setStateSend(Data::DISABLED); // stop sending data until next minute
				}
				continue;
			} //plen check

			// check for incomming messages not processed
			// as part of packetloop_arp_icmp_tcp, e.g udp messages
			if (dat_p == 0) { //plen!=0
				udp_client_check_for_dns_answer(ethBuffer, plen);
				continue;
			}

			// server: serve JSON
			if (strncmp("GET /j", (char *)&(ethBuffer[dat_p]), 6) == 0) {
				dat_p = fill_tcp_data_p(ethBuffer,0,PSTR("HTTP/1.0 200 OK\r\nContent-Type: text/html\r\nPragma: no-cache\r\n\r\n"));
				// create webserver page: pay attention to buffers used: buffer and ethBuffer as small in size!
				sprintf_P(buffer, PSTR("{\"data\":{ \"id\":\"%08lX\","), data.getDeviceID());
				dat_p = fill_tcp_data_len(ethBuffer,dat_p, (uint8_t *)buffer, strlen(buffer));
				sprintf_P(buffer, PSTR("\"type\":\"%X\",\"detector\":\"%s\",\"cpm\":%lu,"),DEV_CLASS, aux_detectorName(GEIGER_TUBE), data.getGeigerCPM());
				dat_p = fill_tcp_data_len(ethBuffer,dat_p, (uint8_t *)buffer, strlen(buffer));
#ifdef USE_BME280_SENSOR
				sprintf_P(buffer, PSTR("\"temperature\":%.2f,\"pressure\":%lu,\"humidity\":%.2f,"), data.getTemperature(), data.getPressure(), data.getHumidity());
				dat_p = fill_tcp_data_len(ethBuffer,dat_p, (uint8_t *)buffer, strlen(buffer));
#endif
				sprintf_P(buffer, PSTR("\"uptime\": %lu}}"), time.getTotalSec());
				dat_p = fill_tcp_data_len(ethBuffer,dat_p, (uint8_t *)buffer, strlen(buffer));
			}
			// server: serve mini webpage
			else if (strncmp("GET ",(char *)&(ethBuffer[dat_p]),4)!=0 || strncmp("/ ",(char *)&(ethBuffer[dat_p+4]),2)==0) {
				dat_p = fill_tcp_data_p(ethBuffer,0,PSTR("HTTP/1.0 200 OK\r\nContent-Type: text/html\r\nPragma: no-cache\r\n\r\n"));
				// create webserver page: pay attention to buffers used: buffer and ethBuffer as small in size!
				sprintf_P(buffer, PSTR("<b>uRADMonitor %08lX</b><br>"), data.getDeviceID());
				dat_p = fill_tcp_data_len(ethBuffer,dat_p, (uint8_t *)buffer, strlen(buffer));
				sprintf_P(buffer, PSTR("type:%X hw:%u sw:%u %s<hr>"), DEV_CLASS, VER_HW, VER_SW, aux_detectorName(GEIGER_TUBE));
				dat_p = fill_tcp_data_len(ethBuffer,dat_p, (uint8_t *)buffer, strlen(buffer));
				sprintf_P(buffer, PSTR("radiation:%luCPM<br>"), data.getGeigerCPM());
				dat_p = fill_tcp_data_len(ethBuffer,dat_p, (uint8_t *)buffer, strlen(buffer));
#ifdef USE_BME280_SENSOR
				if (time.getTotalSec() < WARMUP) {
					sprintf_P(buffer, PSTR("Ready in %ds<br><br>"), WARMUP - time.getTotalSec());
					dat_p = fill_tcp_data_len(ethBuffer,dat_p, (uint8_t *)buffer, strlen(buffer));
				} else {
					sprintf_P(buffer, PSTR("temperature:%.2fC<br>pressure:%luPa<br>"), data.getTemperature(), data.getPressure());
					dat_p = fill_tcp_data_len(ethBuffer,dat_p, (uint8_t *)buffer, strlen(buffer));
					sprintf_P(buffer, PSTR("humidty:%.2fRH<br>"), data.getHumidity());
					dat_p = fill_tcp_data_len(ethBuffer,dat_p, (uint8_t *)buffer, strlen(buffer));
				}
#endif
				sprintf_P(buffer, PSTR("voltage:%uV<br>duty:%u%%<br>frequency:%.2fkHz<br>"),data.getInverterVoltage(), data.getInverterDuty() /10, INVERTER_FREQUENCY / 1000.0);
				dat_p = fill_tcp_data_len(ethBuffer,dat_p, (uint8_t *)buffer, strlen(buffer));
				sprintf_P(buffer, PSTR("uptime:%lus wdt:%us/%us<br><br>"), time.getTotalSec(), wd.wdt_get_counter(), wd.wdt_getRebootSeconds());
				dat_p = fill_tcp_data_len(ethBuffer,dat_p, (uint8_t *)buffer, strlen(buffer));
				sprintf_P(buffer,PSTR("ip:%u.%u.%u.%u<br>server:%u.%u.%u.%u<br>"),
						data.getIPLocal()[0],data.getIPLocal()[1],data.getIPLocal()[2],data.getIPLocal()[3],
						data.getIPRemote()[0],data.getIPRemote()[1],data.getIPRemote()[2],data.getIPRemote()[3]);
				dat_p = fill_tcp_data_len(ethBuffer,dat_p, (uint8_t *)buffer, strlen(buffer));
				sprintf_P(buffer,PSTR("interval:%u http:%u %u/%u"), data.getNetworkSendInterval(), data.getNetworkHTTPCode(), data.getNetworkPacketsOK(), data.getNetworkPacketsTotal());
				dat_p = fill_tcp_data_len(ethBuffer,dat_p, (uint8_t *)buffer, strlen(buffer));
				sprintf_P(buffer,PSTR("<hr><a href=\"/j\">JSON</a> [%03u]"), dat_p + 31);
				dat_p = fill_tcp_data_len(ethBuffer,dat_p, (uint8_t *)buffer, strlen(buffer));
				// tcp port 80 end
			} else
				dat_p=fill_tcp_data_p(ethBuffer,0,PSTR("HTTP/1.0 401 Unauthorized\r\nContent-Type: text/html\r\n\r\n<h1>401 Unauthorized</h1>"));
			www_server_reply(ethBuffer, dat_p); // send web page data to client
		}
#endif // USE_ETHERNET
	} // if network data.getStateNetwork() is ok

	return (0);
}  

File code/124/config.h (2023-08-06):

/**
 *	File:       	config.cpp
 *	Version:  		1.0
 *	Date:       	2016
 *	License:		GPL v3
 *	Description:	config file for uRADMonitor code
 *	Project:		uRADMonitor KIT1, a hackable digital sensor monitoring tool with network interface
 *
 *	Copyright 2016 by Radu Motisan, radu.motisan@gmail.com
 *	Copyright 2016 by Magnasci SRL, www.magnasci.com
 *
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
 *	You should have received a copy of the GNU General Public License
 *	along with this program.  If not, see <http://www.gnu.org/licenses/>.
 */

#pragma once

// USER CONFIGURATION SPACE
// additional sensors sample

#define USE_BME280_SENSOR

#define USE_ETHERNET

// user upload credetials, create your account on www.uradmonitor.com/dashboard
// the Dashboard shows the user-id and the user-key
#define				USER_ID					""
#define				USER_KEY				""

// PRIVATE CONFIGURATION SPACE, don't change the values below unless you know what you are doing
// device identification
#define				DEV_CLASS				0x13
#define				VER_SW					124
#define				VER_HW					107

// constants for this device
#define				P_TUBEVOLFB_PIN			PC2		// voltage divider to measure high voltage
#define				P_TUBEVOLFB_R1			10000	// voltage divider to measure high voltage
#define				P_TUBEVOLFB_R2			47		// voltage divider to measure high voltage
#define				GEIGER_TUBE				GEIGER_TUBE_SBM20
#define				WARMUP					0		// initial warmup interval before sensors are ready, use only if needed
#define				READ_INTERVAL			5		// interval in seconds to read sensors

// user interaction
#define				LONG_PRESS				2		// 2 seconds on central button count as a long press
#define 			BACKLIGHT_TIMEOUT		10		// turn backlight in 10 seconds of inactivity to conserve power
#define				WATCHDOG_INTERVAL		600		// seconds to wait until a reboot IF the server doesn't answer

// geiger tube radiation dose thresholds
#define 			DOSE_THRESHOLD_LOW 		0.10
#define 			DOSE_THRESHOLD_NORMAL 	0.20
#define 			DOSE_THRESHOLD_HIGH 	1.00

// uradmonitor upload api
#define				URADMONITOR_SERVER 		"data.uradmonitor.com"
#define 			URADMONITOR_SCRIPT 		"/api/v1/upload/exp/"

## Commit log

2015-10-04 uradmonitor KIT 1.1 update
    [dosimeter.GBL, dosimeter.GBO, dosimeter.GBP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]
2015-10-04 added BOM for PCB 1.1
2016-04-06 added hw pcb-1.1.103
    [dosimeter.GBL, dosimeter.GBO, dosimeter.GBP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]
2016-04-06 structured pcb in separate folder
    [dosimeter.GBL, dosimeter.GBO, dosimeter.GBP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]
2016-10-12 full open source release v1.2.105 under GPL v3
    [dosimeter.GBL, dosimeter.GBO, dosimeter.GBP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]
2016-10-12 bme280 sensor disabled by default, see config.h
2016-10-12 added BOM for 1.2.105 pcb
2017-08-05 issues fixed, sw 123, hw 1.2.106
    [dosimeter.GBL, dosimeter.GBO, dosimeter.GBP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]
2017-08-05 added missing humidity for bme280 in mini webserver
    [config.h, uRADMonitor.cpp]
2023-08-06 HW 1.2.107
    [dosimeter.brd, dosimeter.sch]

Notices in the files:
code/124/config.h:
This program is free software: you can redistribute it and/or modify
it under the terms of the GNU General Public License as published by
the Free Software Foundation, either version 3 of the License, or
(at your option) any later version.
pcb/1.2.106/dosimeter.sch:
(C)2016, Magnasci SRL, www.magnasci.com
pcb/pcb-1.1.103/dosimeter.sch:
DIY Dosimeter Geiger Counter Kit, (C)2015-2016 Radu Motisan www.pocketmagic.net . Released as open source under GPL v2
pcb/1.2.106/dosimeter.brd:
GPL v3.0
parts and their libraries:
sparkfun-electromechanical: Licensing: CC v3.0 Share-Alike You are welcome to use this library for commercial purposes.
